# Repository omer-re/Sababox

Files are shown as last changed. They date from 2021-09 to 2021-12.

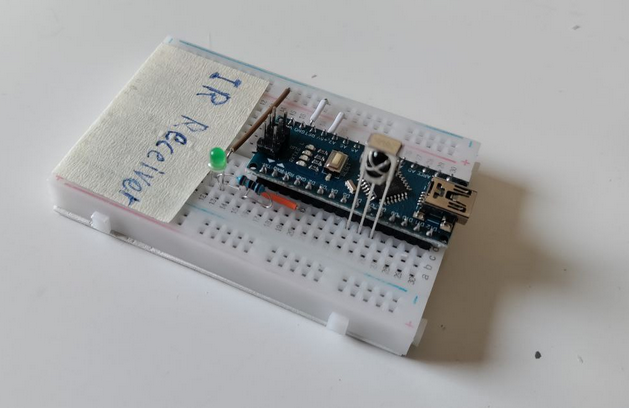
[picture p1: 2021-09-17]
Images/Rx unit.png

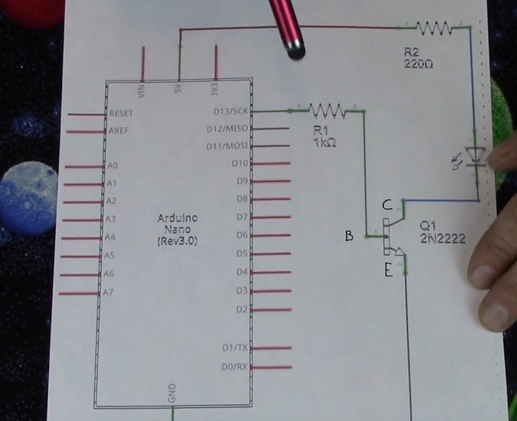
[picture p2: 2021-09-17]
Images/arduino and transistor.png

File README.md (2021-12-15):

# Sababox
Elderly friendly remote control

Watch the demo video

## Arduino official:
 https://blog.arduino.cc/2021/09/28/sababox-is-an-easy-to-use-remote-for-the-elderly

Twitter: https://twitter.com/arduino/status/1442712007577247744

Facebook: https://www.facebook.com/156088694417458/posts/7063631940329731/

## Hackaday:
https://hackaday.com/2021/09/26/elderly-remote-keeps-things-simple/

Twitter: https://twitter.com/hackaday/status/1442081636259086338

Facebook: https://www.facebook.com/hackaday.io/posts/4878315675515004

 Take A look (https://blog.arduino.cc/2021/09/28/sababox-is-an-easy-to-use-remote-for-the-elderly)
 Take A look (https://hackaday.com/2021/09/26/elderly-remote-keeps-things-simple/)

# Please check our Instructable page:
https://www.instructables.com/Sababox-Elderly-Friendly-Remote-Control/
### Our Instructable tutorial won "editor's choice of the day" on the first day it was published!
 Take A look (https://www.instructables.com/Sababox-Elderly-Friendly-Remote-Control/)

## Project presentation:

## Project poster:

## Project video: (https://www.youtube.com/watch?v=u9Db-l06_1o)

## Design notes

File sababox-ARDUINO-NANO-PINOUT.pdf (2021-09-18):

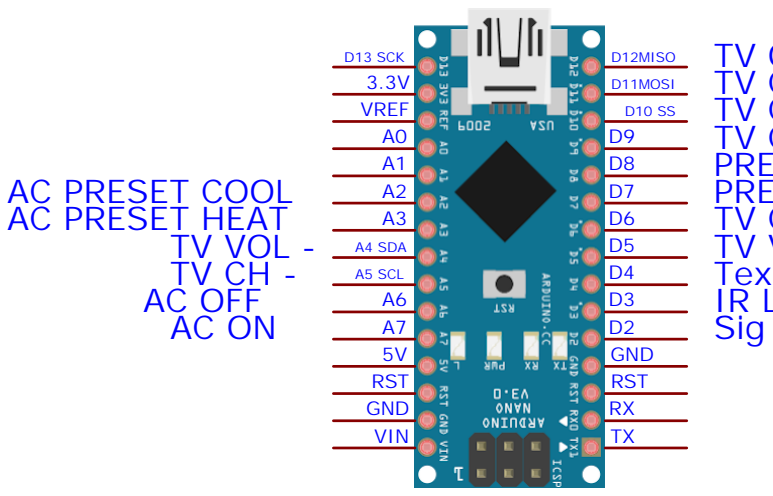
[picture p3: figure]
Sig; AC OFF; TV VOL -; AC PRESET HEAT; AC PRESET COOL; RST; GND; D11MOSI; D13 SCK; D12MISO; 3.3V VREF A0 A1 A2 A3; A4 SDA; A5 SCL A6 A7 5V RST GND VIN

TV ON/OFF
TV CH 11
TV CH 12
TV CH 13
PRESET 2
PRESET 1
TV CH +
TV VOL +
Text
IR LED

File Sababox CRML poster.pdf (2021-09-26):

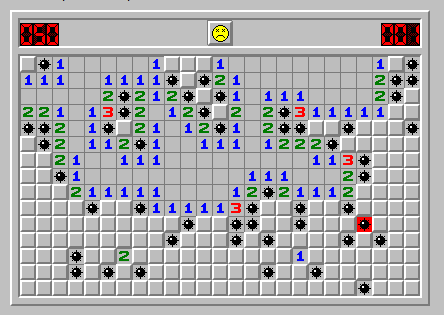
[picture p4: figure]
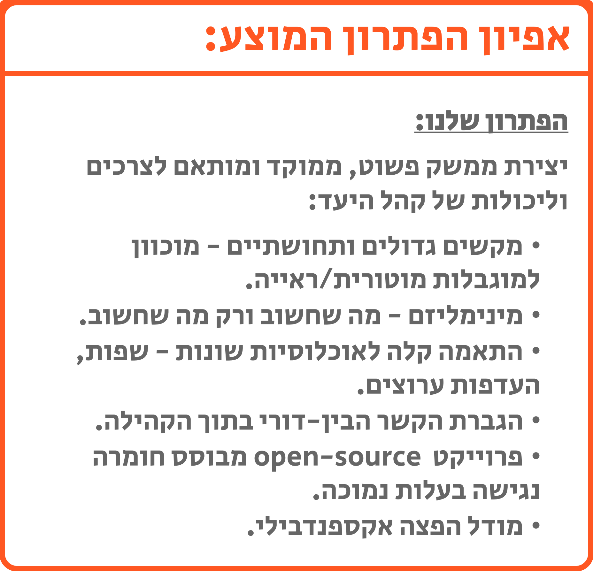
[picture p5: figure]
אפיון הפתרון המוצע:; הפתרון שלנו: יצירת ממשק פשוט, ממוקד ומותאם לצרכים וליכולות של קהל היעד: • מקשים גדולים ותחושתיים - מוכוון למוגבלות מוטורית/ראייה. • מינימליזם - מה שחשוב ורק מה שחשוב. • התאמה קלה לאוכלוסיות שונות - שפות, העדפות ערוצים. • הגברת הקשר הבין-דורי בתוך הקהילה. • פרוייקט source-open מבוסס חומרה נגישה בעלות נמוכה. • מודל הפצה אקספנדבילי.

# Who needs it?

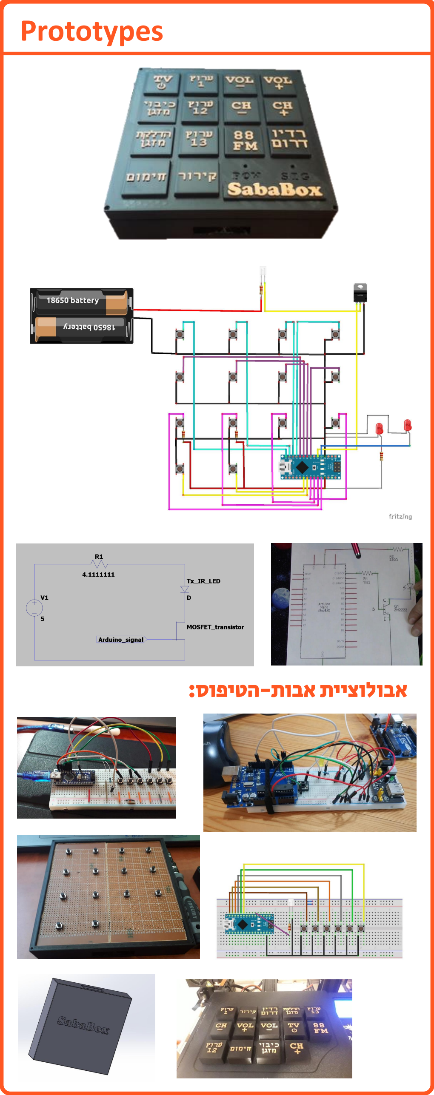
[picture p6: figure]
Prototypes; אבולוציית אבות-הטיפוס:

# Results

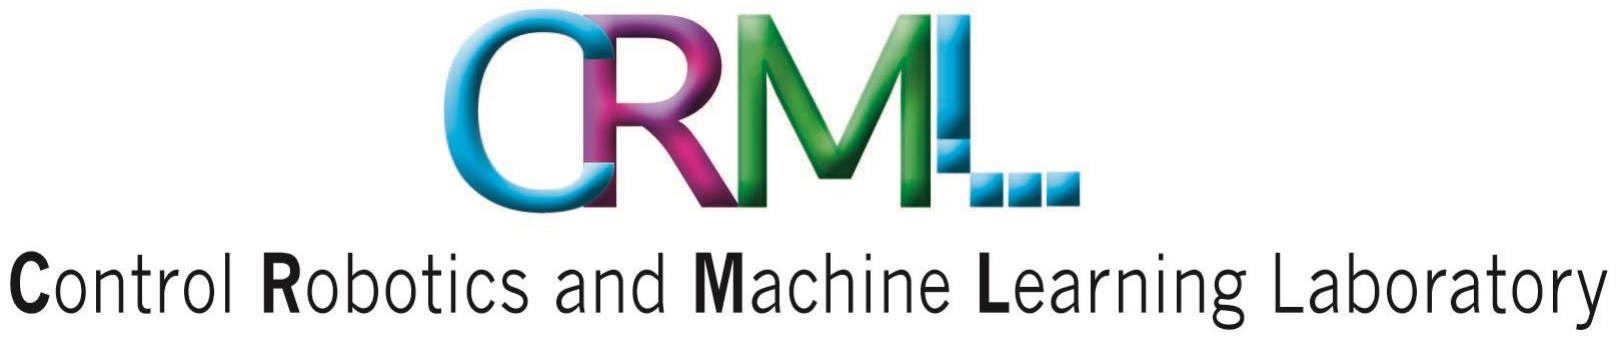
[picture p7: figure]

Elderly friendly remote control.

# Because TV remote shouldn’t feel like a minesweeper board

# By Elad Ifrach & Omer Reuveni, Supervised by Kobi Kohai

# Main challenges:

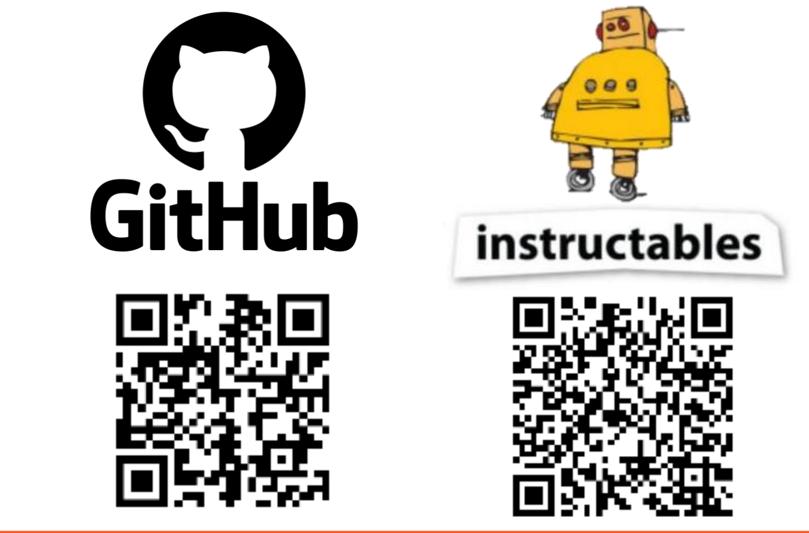
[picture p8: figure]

September 2021

# הצורך + 60 שניות “Grey economy” על

## "כולנו מכירים את סיפורי הזוועה

על שלטי טלוויזיה.

## יש בהם 30 כפתורים ואנחנו )גם הצעירים(

משתמשים בארבעה.

## חוסר ההתאמה בין השלט של הכבלים והשלט של הטלוויזיה מכניס רבים למעגל

קסמים אכזרי שבסופו נשאר רק מסך כחול".

לאנשים מבוגרים יש, במקרים רבים, הכנסה פנויה 'לבזבז' על רכישת מוצרים מתקדמים. מדוע, אם כן, נמנעים רבים מבני גיל הזהב משימוש בטלפונים חכמים, שלטי טלוויזיה מתוחכמים ומוצרים דומים? תתפלאו, אבל זה לא בגלל שהאותיות קטנות מדי. הכל שאלה של כבוד עצמי ופסיכולוגיה חיובית. פרופ' רון נברו הוא מרצה ומעצב עולמי ידידותי לגיל המבוגר, מרצה ומעצב עולמי ידידותי לגיל המבוגר, חתן הפרס היוקרתי Award Network World( והזוכה הישראלי היחיד בכבוד זה( בזכות תרומתו לעתיד העיצוב לגיל הזיקנה. פרופסור במסלול ללימודי מוסמכים בעיצוב תעשייתי בטכניון. נחשב כמעצב תעשייתי בינלאומי, נשיא חב' ltd Touch-Senior. העוסקת בייעוץ לחברות וארגונים באפיון והגדרת צרכים של משתמשים מבוגרים וזקנים לצורך עיצוב מוצרים שירותים, ותקשורת חזותית. כן מכהן כנשיא TM all4design קונסורציום בינלאומי המקדם פתרונות עיצוב עבור האוכלוסייה המבוגרת והזקנה.

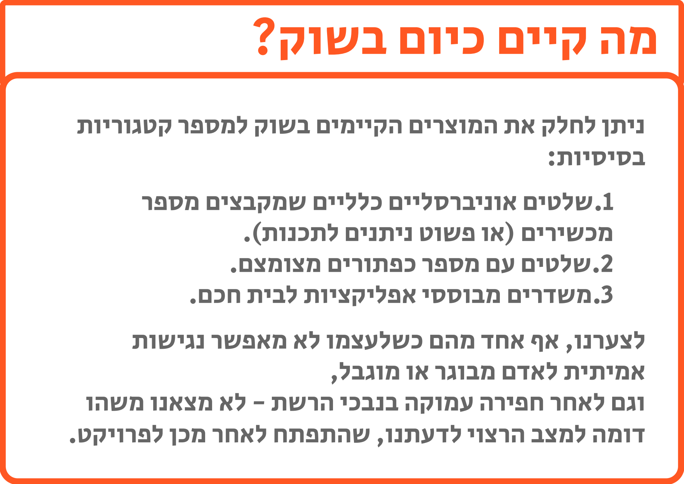
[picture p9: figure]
מה קיים כיום בשוק?; בסיסיות: .1שלטים אוניברסליים כלליים שמקבצים מספר מכשירים )או פשוט ניתנים לתכנות(. .2שלטים עם מספר כפתורים מצומצם. .3משדרים מבוססי אפליקציות לבית חכם.; אמיתית לאדם מבוגר או מוגבל,

## ניתן לחלק את המוצרים הקיימים בשוק למספר קטגוריות

## לצערנו, אף אחד מהם כשלעצמו לא מאפשר נגישות

## וגם לאחר חפירה עמוקה בנבכי הרשת - לא מצאנו משהו

דומה למצב הרצוי לדעתנו, שהתפתח לאחר מכן לפרויקט.

## השגת טווח שידור וזווית שידור

### למרות שכל שלט ביתי סטנדרטי מצליח לשדר בקלות מצידו השני של החדר ובלי צורך בכיוון מאוד ישיר- הופתענו לגלות כמה מאתגר היה להשיג טווח

שידור שכזה וטולרנס גבוה לזווית השידור.

### מכיוון שתכננו את המכשיר להיות מונח על גבי שולחן- הדבר חשוב פי כמה

משום שלא תמיד נוכל להבטיח זווית מדוייקת.

### הפתרון דרש שימוש בנורות transmitter IR בעלות עמידות לזרם גבוה )עד

כדי 1 אמפר( וגם טרנזיסטור שמתאים לזרמים כאלו וקצבי עבודה מתאימים.

### במוצר הסופי נורת השידור מופעלת ע"י מעגל נפרד שמספק את ההספק הדרוש ומבטיח שידור חזק במיוחד. ישנה הכנה במארז לנורות נוספות למקרה שבו תידרש זווית שידור קיצונית, אך לא מצאנו בכך צורך ולכן לא

מחוברות שם נורות בשלב זה.

## מחסור בזיכרון אחסון - partition management Memory

בעיית זיכרון איחסון לוקטורים הארוכים שנדרשים עבור רבים מפקודות המזגנים. החקירה הביאה אותנו להבנת מודל חלוקת הזיכרון של הלוח:

There are three pools of memory in the microcontroller used on avr-based Arduino boards :

•Flash memory (program space), is where the Arduino sketch is stored. •SRAM (static random access memory) is where the sketch creates and manipulates variables when it runs.
•EEPROM is memory space that programmers can use to store long-term information. [Non-volatile]
מכיוון שמירב הזיכרון הדרוש לנו מורכב מוקטורים קבועים של הסיגנלים ואין צורך לגשת אליהם בגישת כתיבה - הבנו שהפתרון הפשוט והנוח יהיה שימוש ב-space program. המימוש פשוט יחסית ונדרשו שינויים מינוריים בקוד.

בכל פעם שרוצים להשתמש במידע מהזיכרון ב- space program עלינו להעתיק את המידע תחילה לזיכרון העבודה (SRAM )ורק לאחר מכן ניתן לעבוד איתו.
האתגר המרכזי בבעייה הזו הינו שהקומפיילר לא מספק שום חיווי על תקלה כזו על אף שמדובר במצב שניתן לחזות כבר בזמן קומפילציה. הקומפילציה והצריבה עוברות בצורה מוצלחת, אך לא ניתן לבצע את הפעולות בפועל.

## מחסור בזיכרון עבודה - overflow buffer IR

בעיית זיכרון איחסון ושליפה לוקטורים הארוכים שנדרשים עבור רבים מפקודות המזגנים. לאחר חקירה הבנו כי ה- buffer של ספריית ה- IR מוגבל ל100- איברים ולכן לא מצליח להתמודד עם סיגנל ארוך יותר של מזגן. שלטים של מזגנים )ובהכללה- שלטים עם תצוגה( אינם שולחים רק את "השינוי" שנלחץ )למשל "העלה ווליום"( אלא משדרים בכל לחיצה את וקטור המצבים שמתאר את כלל הפרמטרים השונים שהם מציגים. אם וקטור של פקודה בטלוויזיה אורכו כ67- איברים, אות של מזגן דורש כ190- איברים. הופתענו מכמה מעט מידע היה על הנושא באינטרנט וכמה קשה היה למצוא פתרונות אפשריים.
פתחנו את קבצי הספרייה וחקרנו אותם עד אשר מצאנו את הפרמטר שלפיו נוצרים אותם וקטורים של buffer.
לאחר מספר נסיונות הצלחנו להגדיר אותם מחדש כך שיעמדו בכל האילוצים הנוספים וגם יצליחו לקלוט את סיגנלי המזגן. כתוצאה מכך הבנו שכדי למנוע בעיות דומות למי שינסה לשחזר את הפרוייקט בעתיד ולייצר לעצמו מכשיר כזה עלינו "להקפיא" מצב ולייצר גרסה של הספרייה לאחר השינויים, ולשנות את הקוד כך שידע לפנות אליה ולא לספרייה המקורית.

## כפתורים על פינים אנלוגיים לא מגיבים כמצופה

הגורם לבעיה: מסתבר שפינים 7A6,A הם הפינים היחידים בלוח שאינם כוללים in built .pullup resistors
ניסינו להשתמש בפינים האנלוגיים לקלט בינארי אך בפינים מסויימים קיבלנו הבהובים והמון רעש על הסיגנל. בפועל מסתבר שאין להם נגד מובנה, ולכן הפעולה
. | עבורם | אפקטיבית | איננה | pinMode(A6,INPUT_PULLUP)
חמור מכך, לא רק שהמידע על כך איננו מופיע בתיעוד הרשמי הסטנדרטי של ארדואינו -בתיעוד מופיע הסבר הפוך לחלוטין ברוח "לכל הפינים האנלוגיים קיימים pullup in-built resistors בדיוק כמו לפינים הדיגיטליים". במציאות הבעיה שנגרמה הייתה "הבהובים" על הפינים האלו, כלומר דימוי של "לחיצות" שלא באמת התרחשו, רעשים שלא דוכאו ע"י הנגד שנועד לשם כך )בדיוק הסיבה שבגללה ה-practice best היא לחבר נגד לכל כפתור בכדי למנוע רעש(. לאחר הבנת הבעיה הפתרון היה פשוט יחסית- הלחמת נגד בעצמנו.

# SabaBox

# מידע נוסף, תיעוד ופרטי מימוש:

זהו ג'ו,

## שכן מבוגר שהיה אחד ממקורות ההשראה לפרוייקט מדגים את בעיית המסך הכחול שאנו מנסים לפתור במהלך אחד ממפגשי הבדיקה שעשינו איתו על מנת לקבל פידבקים ולהתרשם מחוויית

המשתמש.

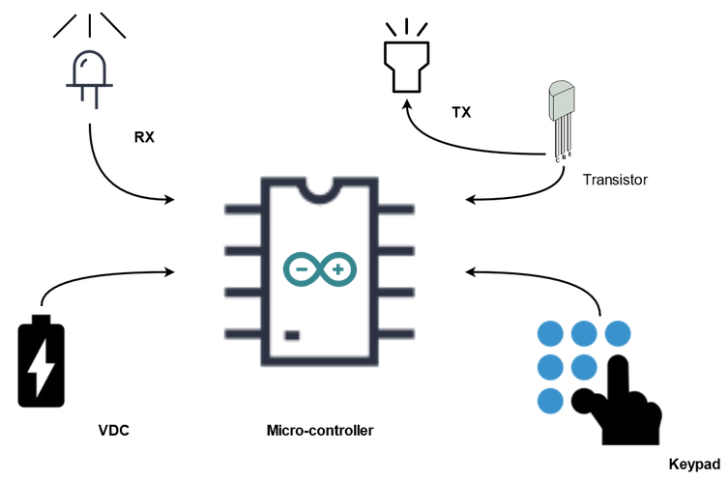
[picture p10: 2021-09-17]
Images/basic sketch.png

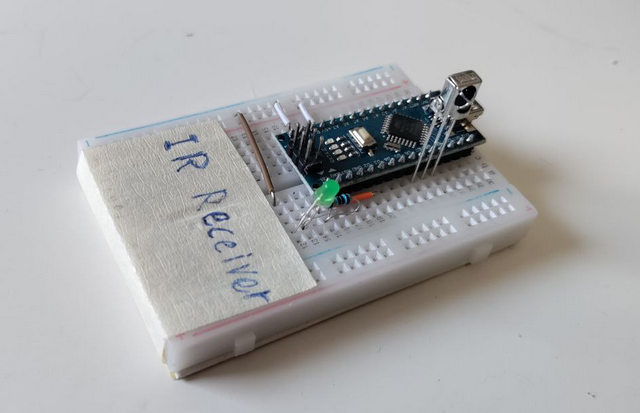
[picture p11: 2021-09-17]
Images/Rx unit2.png

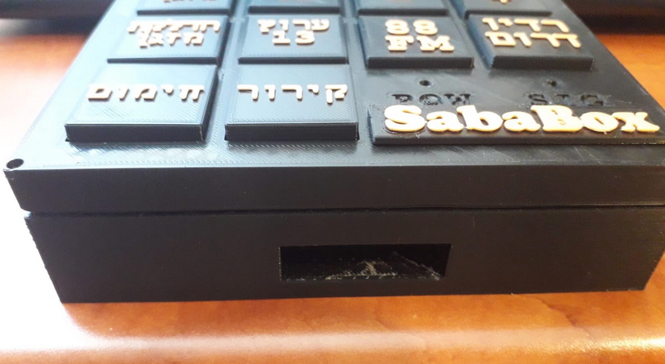
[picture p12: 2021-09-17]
Images/service access.png

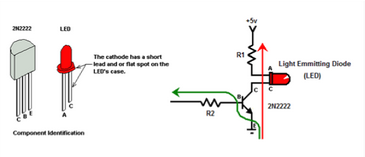
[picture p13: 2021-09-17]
Images/diode and transistor.png

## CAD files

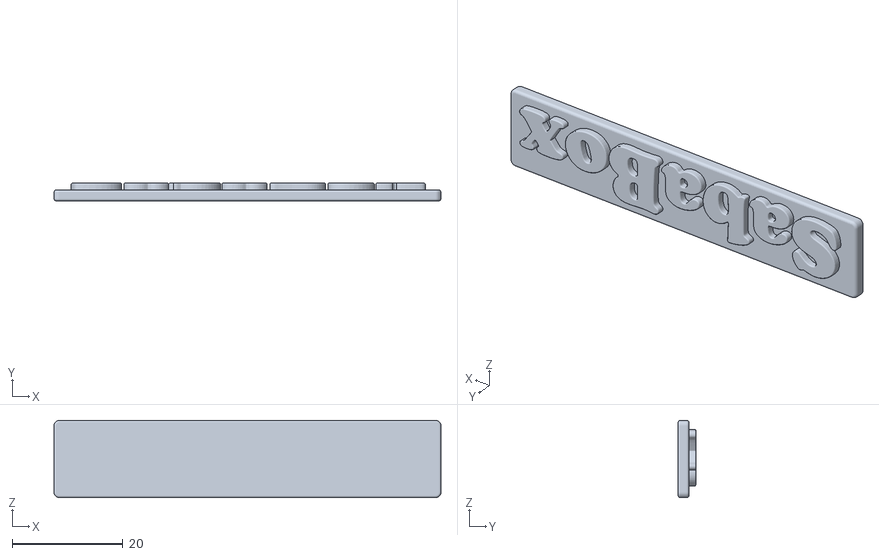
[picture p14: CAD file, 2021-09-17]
3D_printing_files/badge_14_70.STL
70.0 x 3.20 x 14.0

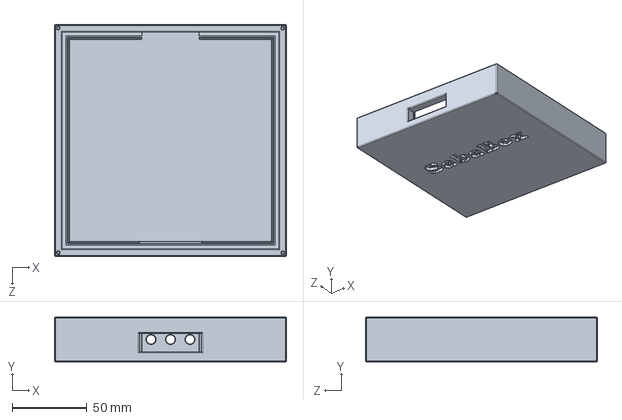
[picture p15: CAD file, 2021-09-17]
3D_printing_files/box/bottom v1 with hole.SLDPRT
155.0 x 30.0 x 155.0 mm

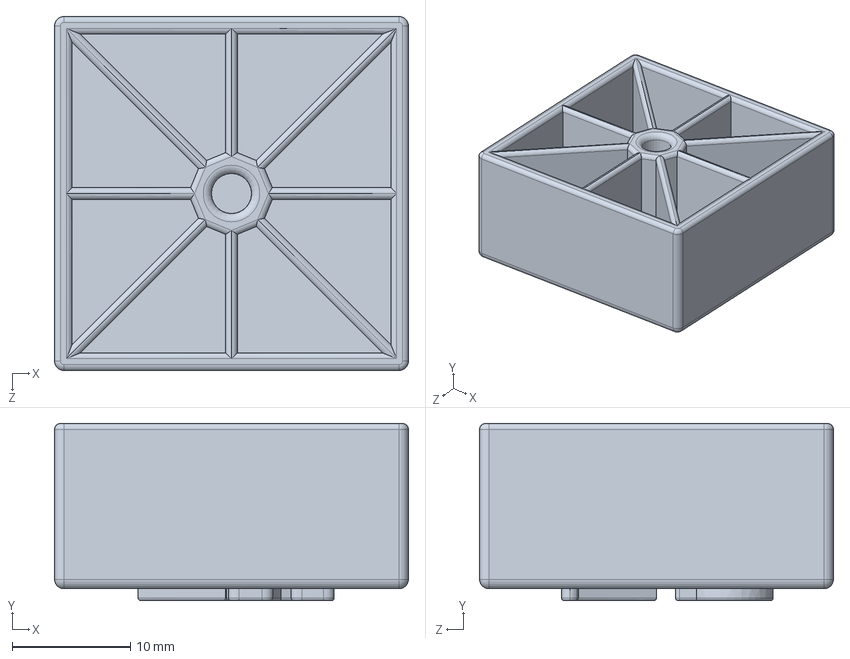
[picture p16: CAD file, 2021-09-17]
3D_printing_files/buttons/30_30_button_TV_onoff.SLDPRT
30.0 x 15.0 x 30.0 mm

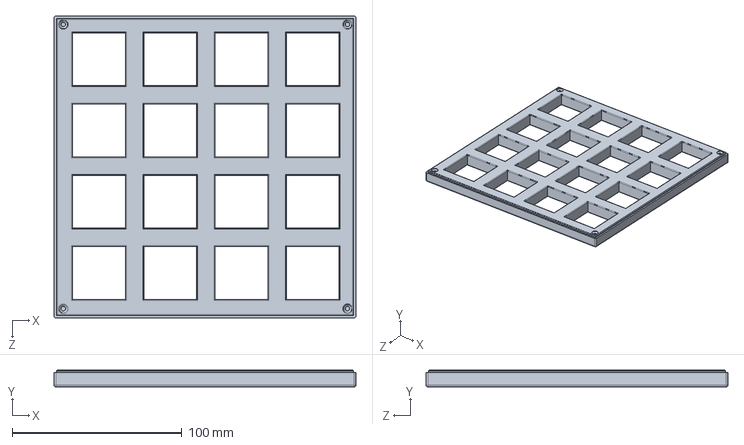
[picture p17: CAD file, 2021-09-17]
3D_printing_files/grid/grid_4X4_30mmButtons_v0.SLDPRT
178.0 x 10.0 x 178.0 mm

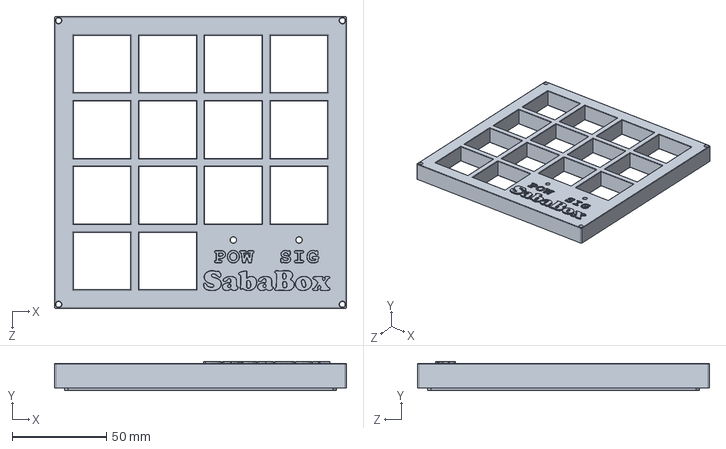
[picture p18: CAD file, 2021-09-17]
3D_printing_files/grid/finalgrid_30dot4_holes.SLDPRT
155.0 x 15.5 x 155.0 mm

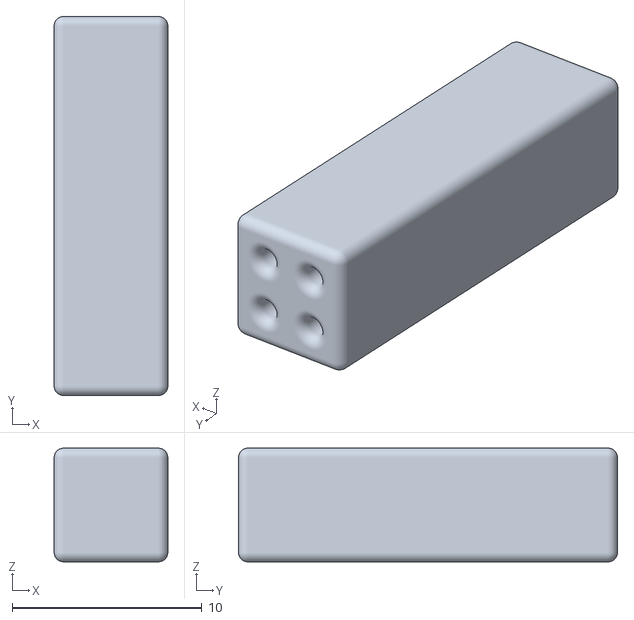
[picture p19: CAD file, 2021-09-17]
3D_printing_files/post.STL
6.00 x 20.0 x 6.00

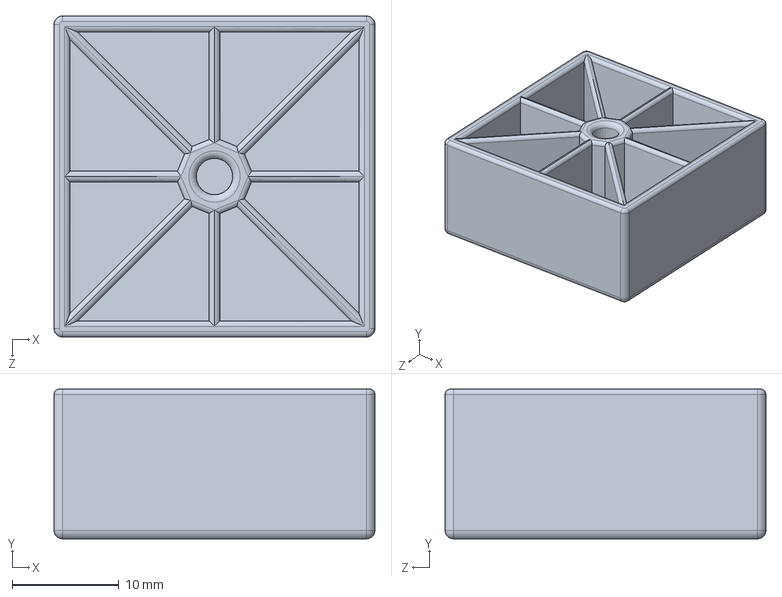
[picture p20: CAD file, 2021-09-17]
3D_printing_files/buttons/Generic30_30_button.SLDPRT
30.0 x 14.0 x 30.0 mm

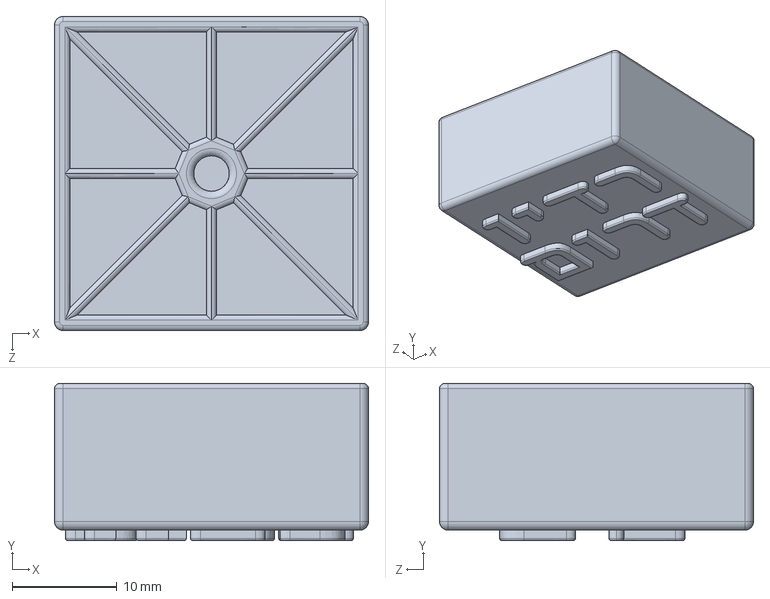
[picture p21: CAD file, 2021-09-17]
3D_printing_files/buttons/30_30_button_RADIO_DAROM.SLDPRT
30.0 x 15.0 x 30.0 mm

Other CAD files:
3D_printing_files/buttons/30_30_button_ARUTZ_1.SLDPRT
3D_printing_files/buttons/30_30_button_vol_plus.SLDPRT
3D_printing_files/buttons/30_30_button_ch_minus.SLDPRT
3D_printing_files/buttons/30_30_button_vol_minus.SLDPRT
3D_printing_files/buttons/30_30_button_KIRUR.SLDPRT
3D_printing_files/buttons/30_30_button_ch_plus.SLDPRT
3D_printing_files/buttons/30_30_button_ARUTZ_13.SLDPRT
3D_printing_files/buttons/30_30_button_HIMUM.SLDPRT
3D_printing_files/buttons/30_30_button_KIBUI_MAZGAN.SLDPRT
3D_printing_files/buttons/30_30_button_ARUTZ_12.SLDPRT
3D_printing_files/box/bottom v1 with hole.STL
3D_printing_files/buttons/30_30_button_88_fm.SLDPRT
3D_printing_files/buttons/30_30_button_HADLEK_MAZGAN.SLDPRT
3D_printing_files/buttons/stls/30_30_button_88_fm.STL
3D_printing_files/buttons/stls/30_30_button_ARUTZ_1.STL
3D_printing_files/buttons/stls/30_30_button_ARUTZ_12.STL
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

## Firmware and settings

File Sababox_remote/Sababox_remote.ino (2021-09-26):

//
// Created by omerr on 08/08/2021.
//

// IRremote.h version 3.1
// a little newer

#include "IRremote.h"
#include <avr/pgmspace.h>
#include <Arduino.h>

#define IR_SEND_PIN 3
#define SIG_PIN 2
//#define LED_PIN 2 //NOTE: this is just a regular indication led- has nothing to the with IR nor with the actual operation

#define TV_ONOFF_PIN 12 //ENABLED
#define TV_CH1_PIN 11 //ENABLED
#define TV_CH12_PIN 10 //ENABLED -MOCKUP-ELADS TV CHANEL 2 
#define TV_CH13_PIN 9 //ENABLED -MOCKUP-ELADS TV CHANEL 3 
#define FM88_PIN 8 // used as "FIX ME"
#define DAROM_PIN 7 //DISABLED
#define TV_CH_PLUS_PIN 6 //ENABLED
#define TV_VOL_PLUS_PIN 5 //ENABLED

#define TV_CH_MINUS_ANALOG_PIN  A5 //ENABLED
#define TV_VOL_MINUS_ANALOG_PIN  A4 //ENABLED

#define AC_ON_ANALOG_PIN A7 //ENABLED
#define AC_OFF_ANALOG_PIN A6 //ENABLED
#define AC_HEAT_ANALOG_PIN A3 //ENABLED
#define AC_COOL_ANALOG_PIN A2 //ENABLED

#define DELAY_BETWEEN_PRESSES 500

//IRsend irsend;
//decode_results results;

void flashSig() {
  // Serial.print("flash\n");
  for (size_t i = 0; i < 5; i++) {
    digitalWrite(SIG_PIN, HIGH);
    delay(50);
    digitalWrite(SIG_PIN, LOW);
    delay(50);
  }
  digitalWrite(SIG_PIN, LOW);

}

void flashSig_ready() {
  // Serial.print("flash\n");
  for (size_t i = 0; i < 5; i++) {
    digitalWrite(SIG_PIN, HIGH);
    delay(800);
    digitalWrite(SIG_PIN, LOW);
    delay(200);
  }
  for (size_t i = 0; i < 2; i++) {
    digitalWrite(SIG_PIN, HIGH);
    delay(50);
    digitalWrite(SIG_PIN, LOW);
    delay(50);
  }
  digitalWrite(SIG_PIN, LOW);

}

int two_digit_channel(const uint16_t *digit1_vector, const uint16_t *digit2_vector, String signal_name) {
    // print to serial monitor as an indication
    Serial.print("Tx: ");
    Serial.print(signal_name);
    Serial.print("\n");

    // transmitting
    Serial.print("Sending");
    IrSender.sendRaw(digit1_vector, sizeof(digit1_vector) / sizeof(digit1_vector[0]), 38);
    delay(600);
    IrSender.sendRaw(digit2_vector, sizeof(digit2_vector) / sizeof(digit2_vector[0]), 38);


}

// HOT  
const PROGMEM uint16_t CH1[67] =    {8880,4470, 530,620, 530,570, 530,570, 530,620, 530,1720, 530,1670, 530,620, 530,570, 530,570, 530,620, 530,570, 530,570, 530,1720, 530,1720, 530,570, 530,620, 530,1670, 530,620, 530,570, 530,1720, 530,1720, 530,570, 530,570, 530,620, 530,570, 530,1720, 530,1670, 530,620, 530,570, 530,1720, 530,1720, 530,1670, 530};  // Protocol=NEC Address=0x3030 Command=0x19 Raw-Data=0xE6193030 32 bits LSB first
const PROGMEM uint16_t CH2[67] =    {8930,4470, 530,620, 480,620, 530,570, 530,620, 480,1720, 530,1720, 530,570, 530,570, 530,620, 480,620, 530,620, 480,620, 480,1770, 480,1720, 530,570, 530,620, 480,620, 480,1770, 480,570, 530,1720, 530,1720, 530,570, 530,570, 530,620, 530,1670, 530,620, 480,1720, 530,620, 480,620, 530,1720, 480,1720, 530,1720, 530};  // Protocol=NEC Address=0x3030 Command=0x1A Raw-Data=0xE51A3030 32 bits LSB first
const PROGMEM uint16_t CH3[67] =    {8980,4420, 580,570, 530,570, 580,520, 580,570, 530,1670, 580,1670, 530,570, 580,520, 580,570, 530,570, 530,570, 580,570, 530,1670, 530,1720, 480,620, 530,570, 530,1720, 530,1720, 480,620, 480,1770, 480,1720, 530,620, 480,620, 480,620, 530,570, 530,620, 480,1720, 530,620, 480,620, 480,1770, 480,1720, 530,1720, 480};  // Protocol=NEC Address=0x3030 Command=0x1B Raw-Data=0xE41B3030 32 bits LSB first
const PROGMEM uint16_t chPlus[67] =   {8880,4520, 530,570, 530,570, 530,620, 480,620, 530,1670, 530,1770, 480,570, 530,620, 530,570, 530,620, 480,570, 530,620, 530,1670, 530,1720, 530,570, 530,620, 530,570, 530,620, 480,620, 480,1770, 480,570, 530,620, 530,570, 530,620, 480,1720, 530,1720, 480,1720, 530,620, 480,1720, 530,1720, 530,1670, 530,1720, 530};  // Protocol=NEC Address=0x3030 Command=0x8 Raw-Data=0xF7083030 32 bits LSB first
const PROGMEM uint16_t chMinus[67] =  {8930,4470, 580,570, 530,570, 530,570, 530,620, 530,1670, 530,1720, 530,570, 530,620, 530,570, 530,570, 530,570, 530,620, 530,1670, 530,1720, 530,570, 530,570, 580,1670, 580,520, 580,570, 530,1670, 530,570, 580,570, 530,570, 580,520, 580,520, 580,1670, 580,1670, 580,520, 580,1670, 580,1620, 580,1670, 580,1620, 580};  // Protocol=NEC Address=0x3030 Command=0x9 Raw-Data=0xF6093030 32 bits LSB first

// AC
const PROGMEM uint16_t ACon[99] =     {4380, 4370, 480, 1670, 480, 620, 480, 1670, 480, 1670, 530, 570, 480, 620, 480, 1670, 480, 620, 530, 520, 530, 1670, 480, 620, 480, 620, 430, 1720, 480, 1670, 480, 570, 530, 1670, 530, 570, 480, 620, 480, 1620, 530, 1670, 480, 1720, 430, 1720, 480, 1670, 480, 1670, 530, 1670, 480, 1720, 430, 620, 480, 570, 480, 620, 480, 620, 480, 620, 430, 620, 530, 620, 430, 620, 480, 570, 480, 620, 480, 620, 480, 620, 430, 670, 430, 670, 430, 1670, 480, 1720, 430, 1720, 480, 1720, 430, 1670, 480, 1720, 480, 1670, 480, 1670, 530}; // Protocol=SAMSUNG Address=0xB24D Command=0x3B2 Raw-Data=0x3FCB24D 48 bits LSB first
const PROGMEM uint16_t ACoff[99] =    {4330, 4420, 480, 1670, 480, 620, 480, 1670, 480, 1720, 480, 570, 480, 620, 480, 1670, 480, 620, 530, 570, 480, 1670, 480, 620, 480, 620, 430, 1720, 480, 1670, 480, 620, 480, 1670, 530, 570, 480, 1670, 480, 1720, 430, 1720, 480, 1670, 480, 620, 480, 1670, 480, 1720, 480, 1670, 480, 620, 430, 620, 480, 620, 480, 620, 480, 1670, 480, 620, 480, 570, 530, 1670, 480, 1670, 480, 1670, 480, 620, 480, 620, 430, 620, 480, 620, 480, 620, 480, 620, 430, 620, 480, 620, 480, 1670, 480, 1720, 430, 1720, 480, 1670, 480, 1670, 530}; // Protocol=SAMSUNG Address=0xB24D Command=0x21B2 Raw-Data=0x21DEB24D 48 bits LSB first
const PROGMEM uint16_t ACheat[99] =   {4330, 4420, 480, 1670, 480, 620, 480, 1670, 480, 1670, 530, 570, 480, 620, 480, 1670, 480, 620, 530, 520, 530, 1670, 480, 620, 480, 620, 430, 1670, 530, 1670, 480, 620, 480, 1670, 530, 520, 530, 620, 480, 1620, 530, 1670, 480, 1670, 480, 1720, 480, 1670, 480, 1670, 530, 1670, 480, 1670, 480, 620, 480, 570, 480, 620, 480, 570, 530, 570, 480, 620, 530, 1620, 480, 620, 480, 620, 480, 1670, 480, 1670, 480, 1670, 530, 620, 430, 620, 530, 570, 480, 1670, 480, 1720, 480, 570, 480, 620, 480, 570, 530, 1670, 480, 1670, 530}; // Protocol=SAMSUNG Address=0xB24D Command=0x3B2 Raw-Data=0x3FCB24D 48 bits LSB first
const PROGMEM uint16_t ACcool[99] =   {4330, 4370, 580, 1620, 580, 470, 580, 1620, 580, 1570, 580, 520, 580, 470, 580, 1620, 580, 470, 530, 570, 580, 1570, 580, 520, 580, 520, 580, 1570, 580, 1570, 580, 520, 580, 1620, 480, 570, 580, 520, 580, 1570, 580, 1570, 580, 1620, 580, 1570, 580, 1570, 580, 1620, 530, 1620, 580, 1570, 580, 520, 580, 520, 530, 520, 580, 520, 580, 520, 580, 470, 580, 520, 580, 520, 580, 520, 530, 520, 580, 520, 580, 520, 580, 470, 580, 520, 580, 1570, 580, 1620, 580, 1570, 580, 1620, 530, 1620, 530, 1620, 580, 1570, 580, 1570, 580}; // Protocol=SAMSUNG Address=0xB24D Command=0x3B2 Raw-Data=0x3FCB24D 48 bits LSB first

// TV
const PROGMEM uint16_t onOff[67] =     {8930,4520, 530,570, 530,570, 530,570, 530,570, 530,570, 530,570, 530,570, 530,570, 480,1720, 530,1670, 530,1670, 530,620, 480,1720, 480,1720, 480,1720, 530,1670, 530,570, 530,520, 530,1720, 530,1670, 530,570, 530,570, 530,570, 530,570, 530,1670, 530,1720, 530,520, 530,570, 580,1620, 530,1720, 480,1720, 480,1720, 530};  // Protocol=NEC Address=0xF700 Command=0xC Raw-Data=0xF30CF700 32 bits LSB first
const PROGMEM uint16_t TV_ch1[67] = {4480,4520, 480,1720, 530,1720, 480,1720, 530,620, 480,620, 480,620, 480,620, 530,620, 480,1720, 530,1720, 480,1720, 530,570, 530,620, 480,620, 480,620, 530,570, 530,620, 480,620, 480,1720, 530,620, 480,620, 480,620, 530,570, 530,620, 480,1720, 530,1720, 480,620, 480,1720, 530,1720, 480,1770, 480,1720, 480,1770, 480};  // Protocol=SAMSUNG Address=0x707 Command=0x4 Raw-Data=0xFB040707 32 bits LSB first
const PROGMEM uint16_t TV_source[67] = {8930,4520, 480,620, 480,620, 480,620, 480,620, 480,620, 480,620, 480,620, 480,570, 530,1720, 480,1720, 480,1670, 530,620, 480,1720, 530,1670, 530,1720, 480,1720, 480,620, 480,570, 580,520, 530,1720, 480,1720, 480,620, 480,620, 480,620, 480,1720, 480,1720, 480,1720, 530,570, 530,570, 530,1670, 530,1720, 480,1720, 480};  // Protocol=NEC Address=0xF700 Command=0x18 Raw-Data=0xE718F700 32 bits LSB first
const PROGMEM uint16_t TV_enter[67] = {8930,4520, 480,570, 530,620, 480,570, 530,620, 480,620, 480,620, 480,620, 480,570, 530,1670, 530,1720, 480,1720, 480,620, 480,1720, 530,1670, 530,1670, 530,1720, 480,1670, 530,1720, 530,1670, 530,570, 530,1670, 530,570, 530,570, 530,570, 530,570, 530,570, 480,620, 480,1720, 530,570, 530,1670, 530,1720, 480,1720, 530};  // Protocol=NEC Address=0xF700 Command=0x17 Raw-Data=0xE817F700 32 bits LSB first
const PROGMEM uint16_t volPlus[67] =  {8930,4520, 480,620, 480,620, 480,620, 480,620, 480,620, 480,570, 530,620, 530,520, 530,1720, 480,1720, 480,1670, 530,570, 580,1670, 530,1670, 530,1720, 480,1720, 480,620, 480,570, 530,570, 530,620, 480,1720, 480,620, 480,570, 530,570, 530,1720, 530,1670, 480,1720, 480,1720, 530,570, 530,1670, 530,1720, 480,1720, 480};  // Protocol=NEC Address=0xF700 Command=0x10 Raw-Data=0xEF10F700 32 bits LSB first
const PROGMEM uint16_t volMinus[67] =   {8980,4470, 530,570, 530,570, 530,570, 530,570, 530,570, 530,570, 530,570, 480,620, 480,1720, 530,1670, 530,1670, 480,670, 480,1720, 480,1720, 480,1720, 530,1670, 530,1670, 530,1720, 480,1720, 480,1720, 480,620, 480,620, 480,620, 480,620, 480,620, 480,620, 430,620, 530,570, 480,1720, 530,1720, 480,1720, 480,1720, 530};  // Protocol=NEC Address=0xF700 Command=0xF Raw-Data=0xF00FF700 32 bits LSB first

// no buffer, stored on flash space
const uint16_t _CH2[67] =  CH2; 
const uint16_t _CH3[67] =  CH3;

uint16_t temp[200] = {0};



void setup()
{
  Serial.begin(9600);
  pinMode(TV_ONOFF_PIN, INPUT_PULLUP);
  pinMode(TV_CH1_PIN, INPUT_PULLUP);
  pinMode(TV_CH12_PIN, INPUT_PULLUP);
  pinMode(TV_CH13_PIN, INPUT_PULLUP);
  pinMode(FM88_PIN, INPUT_PULLUP);
  pinMode(DAROM_PIN, INPUT_PULLUP);
  pinMode(TV_CH_PLUS_PIN, INPUT_PULLUP);
  pinMode(TV_VOL_PLUS_PIN, INPUT_PULLUP);

  pinMode(TV_CH_MINUS_ANALOG_PIN, INPUT_PULLUP);
  pinMode(TV_VOL_MINUS_ANALOG_PIN, INPUT_PULLUP);

  pinMode(AC_ON_ANALOG_PIN, INPUT_PULLUP);
  pinMode(AC_OFF_ANALOG_PIN, INPUT_PULLUP);
  pinMode(AC_HEAT_ANALOG_PIN, INPUT_PULLUP);
  pinMode(AC_COOL_ANALOG_PIN, INPUT_PULLUP);

  pinMode(SIG_PIN, OUTPUT);
  digitalWrite(SIG_PIN, LOW);
  IrSender.begin(IR_SEND_PIN, ENABLE_LED_FEEDBACK);

  // indication for "READY"
  flashSig_ready();
}

void loop() {
  delay(50);
  if (LOW == digitalRead(TV_ONOFF_PIN)) {
    flashSig();
    memcpy_P(temp, onOff, sizeof(onOff));
    IrSender.sendRaw(temp, sizeof(onOff) / sizeof(onOff[0]), 38);
   
  }

  else if (LOW == digitalRead(TV_CH1_PIN)) {
    flashSig();
    memcpy_P(temp, CH1, sizeof(CH1));
    //two_digit_channel(temp,temp,"CH11");
    digitalWrite(SIG_PIN, HIGH);
    IrSender.sendRaw(temp, sizeof(CH1) / sizeof(CH1[0]), 38);
    delay(DELAY_BETWEEN_PRESSES);
    IrSender.sendRaw(temp, sizeof(CH1) / sizeof(CH1[0]), 38);
    digitalWrite(SIG_PIN, LOW);
  }

  else if (LOW == digitalRead(TV_CH12_PIN)) {
    flashSig();
    memcpy_P(temp, CH1, sizeof(CH1));
    //memcpy_P(temp2, CH2, sizeof(CH2));
    digitalWrite(SIG_PIN, HIGH);
    IrSender.sendRaw(temp, sizeof(CH1) / sizeof(CH1[0]), 38);
    delay(DELAY_BETWEEN_PRESSES);
    IrSender.sendRaw(_CH2, sizeof(_CH2) / sizeof(_CH2[0]), 38);
    digitalWrite(SIG_PIN, LOW);
  }

  else if (LOW == digitalRead(TV_CH13_PIN)) {
    flashSig();
    memcpy_P(temp, CH1, sizeof(CH1));
    //memcpy_P(temp2, CH3, sizeof(CH3));
    digitalWrite(SIG_PIN, HIGH);
    IrSender.sendRaw(temp, sizeof(CH1) / sizeof(CH1[0]), 38);
    delay(DELAY_BETWEEN_PRESSES);
    IrSender.sendRaw(_CH3, sizeof(_CH3) / sizeof(_CH3[0]), 38);
    digitalWrite(SIG_PIN, LOW);

  }


// FIX ME DEMO
  else if (LOW == digitalRead(FM88_PIN)) {
    flashSig();
    digitalWrite(SIG_PIN, HIGH);

    
    // press tv ch1
    memcpy_P(temp, TV_ch1, sizeof(TV_ch1));
    IrSender.sendRaw(temp, sizeof(TV_ch1) / sizeof(TV_ch1[0]), 38);
    delay(DELAY_BETWEEN_PRESSES);

    // press tv source X4
    memcpy_P(temp, TV_source, sizeof(TV_source));
    IrSender.sendRaw(temp, sizeof(TV_source) / sizeof(TV_source[0]), 38);
    delay(DELAY_BETWEEN_PRESSES);
    IrSender.sendRaw(temp, sizeof(TV_source) / sizeof(TV_source[0]), 38);
    delay(DELAY_BETWEEN_PRESSES);
    IrSender.sendRaw(temp, sizeof(TV_source) / sizeof(TV_source[0]), 38);
    delay(DELAY_BETWEEN_PRESSES);
    IrSender.sendRaw(temp, sizeof(TV_source) / sizeof(TV_source[0]), 38);
    delay(DELAY_BETWEEN_PRESSES);

    // press tv enter 
    memcpy_P(temp, TV_enter, sizeof(TV_enter));
    IrSender.sendRaw(temp, sizeof(TV_enter) / sizeof(TV_enter[0]), 38);
    delay(DELAY_BETWEEN_PRESSES);

    digitalWrite(SIG_PIN, LOW);

  }

  else if (LOW == digitalRead(TV_CH_PLUS_PIN)) {
    flashSig();
    memcpy_P(temp, chPlus, sizeof(chPlus));
    IrSender.sendRaw(temp, sizeof(chPlus) / sizeof(chPlus[0]), 38);
  }

  else if (LOW == digitalRead(TV_VOL_PLUS_PIN)) {
    flashSig();
    memcpy_P(temp, volPlus, sizeof(volPlus));
    IrSender.sendRaw(temp, sizeof(volPlus) / sizeof(volPlus[0]), 38);
  }

  /*~~~~~~~~~~~~~~~~~~~~~~~~~~~~analog pins~~~~~~~~~~~~~~~~~~~~~~~~~~~~~~~*/
  else if ((analogRead(TV_CH_MINUS_ANALOG_PIN) < 512)) {
    flashSig();
    memcpy_P(temp, chMinus, sizeof(chMinus));
    IrSender.sendRaw(temp, sizeof(chMinus) / sizeof(chMinus[0]), 38);
    //    Serial.print("~a5~\n");
  }

  else if ((analogRead(TV_VOL_MINUS_ANALOG_PIN) < 512)) {
    flashSig();
    memcpy_P(temp, volMinus, sizeof(volMinus));
    IrSender.sendRaw(temp, sizeof(volMinus) / sizeof(volMinus[0]), 38);
    //    Serial.print("~a4~\n");
  }

  else if ((analogRead(AC_OFF_ANALOG_PIN) < 512)) {
    flashSig();
    memcpy_P(temp, ACoff, sizeof(ACoff));

    IrSender.sendRaw(temp, sizeof(ACoff) / sizeof(ACoff[0]), 38);
    //    Serial.print("~a6~\n");
  }

  else if ((analogRead(AC_ON_ANALOG_PIN) < 512)) {
    flashSig();
    memcpy_P(temp, ACon, sizeof(ACon));

    IrSender.sendRaw(temp, sizeof(ACon) / sizeof(ACon[0]), 38);
  }
  
    else if ((analogRead(AC_HEAT_ANALOG_PIN)<512)) {
        flashSig();
    memcpy_P(temp, ACheat, sizeof(ACheat));

      IrSender.sendRaw(temp, sizeof(ACheat) / sizeof(ACheat[0]), 38);
  }
  
    else if ((analogRead(AC_COOL_ANALOG_PIN)<512)) {
        flashSig();
  
    memcpy_P(temp, ACcool, sizeof(ACcool));

      IrSender.sendRaw(temp, sizeof(ACcool) / sizeof(ACcool[0]), 38);
  }
  
  /*~~~~~~~~~~~~~~~~~~~~~~~~~~~~~~~~~~~~~~~~~~~~~~~~~~~~~~~~~~~~~~~~~~~~~~*/

}

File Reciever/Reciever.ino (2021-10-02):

// Reciever_21.8 version

// IRremote.h version 3.1

#include <IRremote.h>
#include <Arduino.h>
#include <FastLED.h>

#define RECV_PIN 5

#define SIG_LED 4 //NOTE: this is just a regular indication led- has nothing to the with IR nor with the actual operation
#define PENDING_LED 6
#define POWER_LED 0 //NOTE: this is just a regular indication led- has nothing to the with IR nor with the actual operation

IRrecv irrecv(RECV_PIN);
decode_results results;

void flash_flash() {
    // led flash as indication
    for (int i = 0; i < 3; i++) {
        digitalWrite(SIG_LED, HIGH);
        delay(90);
        digitalWrite(SIG_LED, LOW);
        delay(90);
    }
}


String sig_name;
void setup() {
    Serial.begin(9600);
    irrecv.enableIRIn(); // Start the receiver

    pinMode(SIG_LED, OUTPUT);
    pinMode(PENDING_LED, OUTPUT);

    Serial.print("RAW_BUFFER_LENGTH\t");Serial.println(RAW_BUFFER_LENGTH);
    flash_flash();
    Serial.println("READY TO GO");
}

void loop() {
    Serial.println("Type signal name: "); 
    while (Serial.available() == 0){
            EVERY_N_MILLISECONDS( 1000 ) {digitalWrite(PENDING_LED, !digitalRead(PENDING_LED));}
      }
    digitalWrite(PENDING_LED, LOW);
    sig_name=Serial.readString();
    Serial.println(sig_name);  
    Serial.println("Now record remote operation: "); 
    irrecv.resume(); // clear buffer to avoid miss-ups

    while (irrecv.available() == 0){ 
      EVERY_N_MILLISECONDS( 1000 ) {digitalWrite(SIG_LED, !digitalRead(SIG_LED));}
    }  

    if (irrecv.decode()) {
        Serial.print("Receiving signal:");
        irrecv.compensateAndPrintIRResultAsCArray(&Serial, sig_name);// prints data about the signal
        delay(1000);
        irrecv.resume(); // Receive the next value
        flash_flash();
 
        Serial.print("Done, next\n");
        

    }

}

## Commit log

2021-09-17 Arduino nano driver
    Serial driver in case your windows doesn't recognize it
2021-09-17 3D printing sketches
    [30_30_button_88_fm.SLDPRT, 30_30_button_88_fm.STL, 30_30_button_ARUTZ_1.SLDPRT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]
2021-09-18 arduino pinout mapping
2021-09-26 Updates after a demo at Joe's apartment
    channel codes for HOT devices.
2021-09-28 Added דיאגרמת שלטים.drawio
2021-10-02 adding pending LED
